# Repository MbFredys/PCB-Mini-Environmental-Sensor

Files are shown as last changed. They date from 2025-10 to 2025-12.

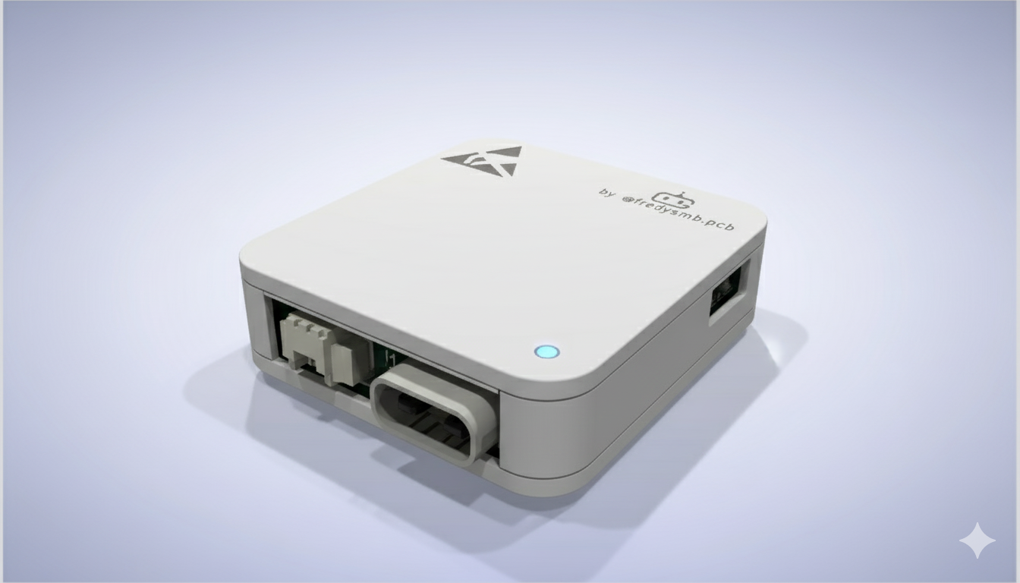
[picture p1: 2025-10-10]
Release/Carcaza 1.png

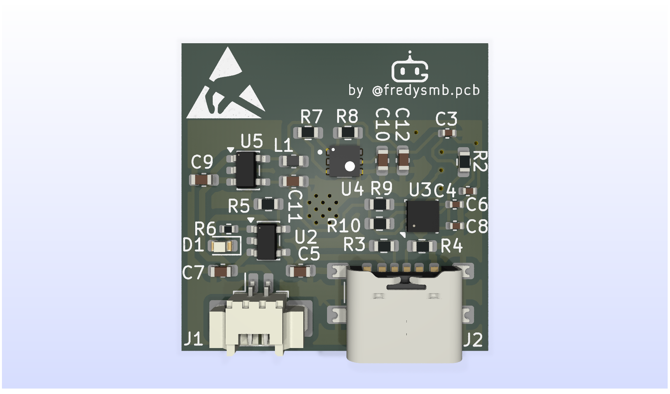
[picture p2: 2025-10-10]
Release/Bottom.png

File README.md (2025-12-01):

# PCB-Mini-Environmental-Sensor


This is a compact environmental monitoring PCB design that enables precise tracking of multiple atmospheric parameters with the following features:

1. 🌡️ Monitors temperature, humidity, and atmospheric pressure using BME280 sensor
2. 💨 Measures air quality and CO2 equivalent with Sensirion SPG40 sensor
3. 📶 WiFi and Bluetooth connectivity via ESP32-C3-VROOM-02 microcontroller
4. 🔋 Battery-powered operation with 3.7V Li-ion battery and USB-C charging
5. ⚡ Efficient power management using TPS62203 step-down converter
6. 🔄 Automatic data logging with cloud connectivity capabilities
7. 💤 Ultra-low power consumption with deep sleep mode
8. 🌧️ Weather-resistant design suitable for indoor and outdoor use

# Usage
To use the environmental sensor node, follow these steps:

  1. Power the device using either the 3.7V battery or USB-C connection
  2. Place the sensor in your desired monitoring location (indoor or outdoor)
  3. Connect to WiFi using the device's configuration interface
  4. Monitor environmental data in real-time through the web dashboard
  5. Analyze historical trends
  6. Receive alerts when environmental parameters exceed safe levels

The device automatically optimizes power consumption by entering deep sleep between measurements, ensuring extended battery life while providing continuous environmental monitoring for smart home, agricultural, and industrial applications.

# Getting Started
To get started with the Environmental Sensor Node PCB design, follow these steps:

  1. Clone this repository to your local machine
  2. Open the PCB design files in your preferred EDA software (KiCAD recommended)
  3. Review the schematic and layout - pay special attention to:
  4. RF antenna keep-out zone for ESP32-C3
  5. I2C routing between sensors and microcontroller
  6. Power distribution network
  7. Send the files to PCBWay for professional fabrication

# Hardware Setup
After receiving your PCBs, solder components in this recommended order:

  1. Power section (TPS62203, MCP73831)
  2. ESP32-C3 module
  3. Sensors (BME280, SPG40)
  4. Passive components and connectors
  5. Program the ESP32-C3 via USB-C connection
  6. Connect a 3.7V Li-ion battery to the battery connector
  7. Test each sensor

# Contributing
If you would like to contribute to the Environmental Sensor Node project, please follow these steps:

  1. Fork this repository
  2. Create a feature branch (git checkout -b feature/improvement)
  3. Make your enhancements - consider:
  4. Power optimization techniques
  5. Additional sensor support
  6. Improved enclosure designs
  7. Localization for different regions
  8. Test your changes thoroughly
  9. Submit a pull request with detailed description

# Areas for Contribution
1. 🔋 Power management algorithms
2. 📡 Wireless protocol optimizations
3. 🌡️ Sensor calibration procedures
4. 🏠 Enclosure designs for different environments
5. 📊 Data visualization interfaces
6. 🔧 Manufacturing improvements

# License
This project is licensed under the CERN Open Hardware Licence Version 2 - Weakly Reciprocal (CERN-OHL-W-2.0).
See the [CERN-OHL-W-2.0 ↗](https://gitlab.com/ohwr/project/cernohl/-/wikis/uploads/82b567f43ce515395f7ddbfbad7a8806/cern_ohl_w_v2.txt) file for more information.

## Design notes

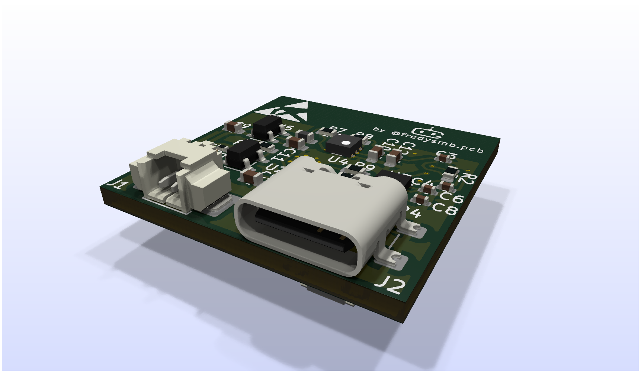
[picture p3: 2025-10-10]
Release/3D-1.png

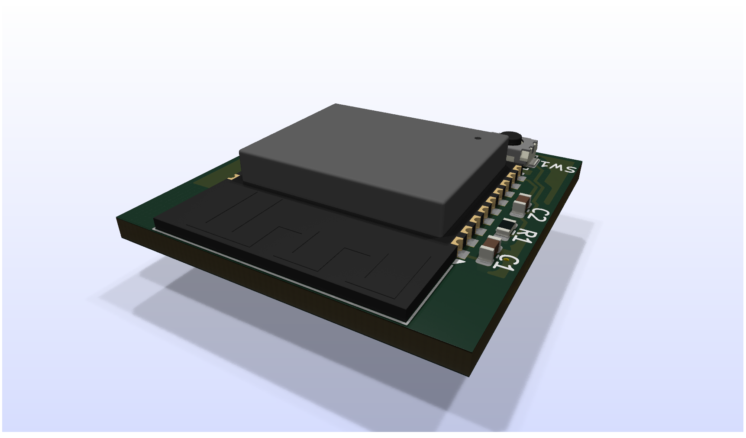
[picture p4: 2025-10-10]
Release/3D-2.png

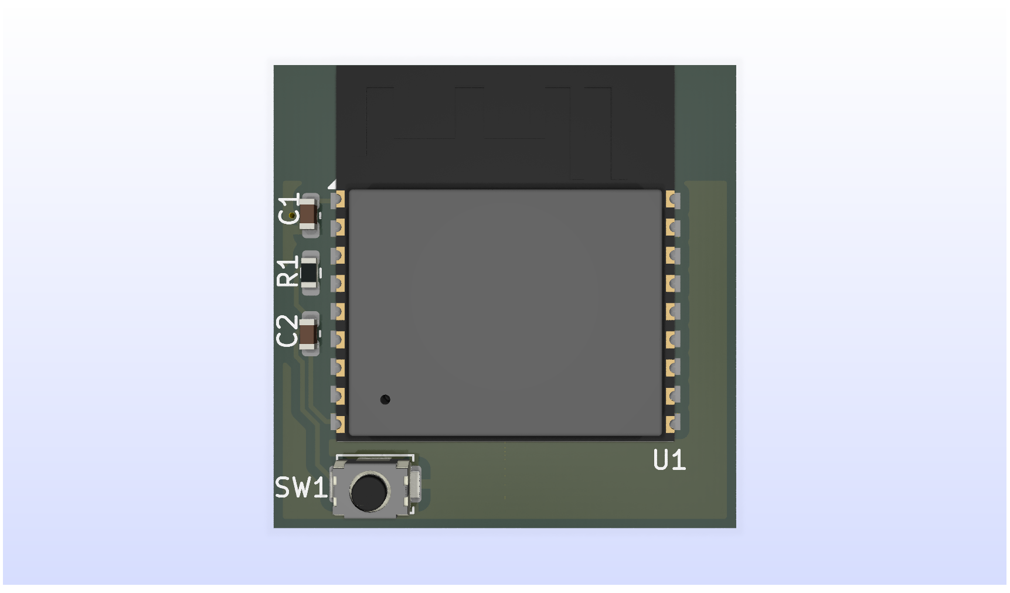
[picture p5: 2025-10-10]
Release/Top.png

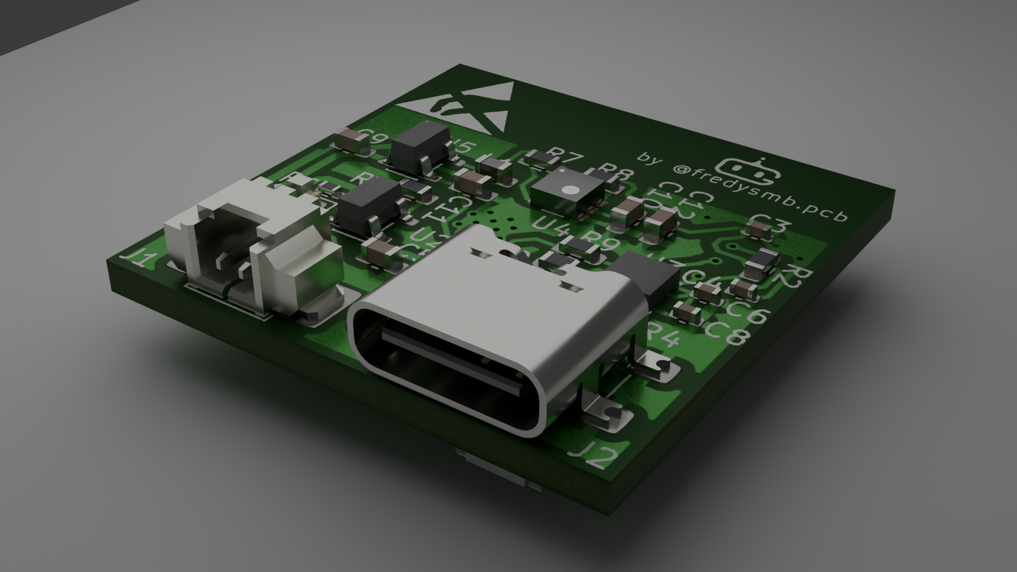
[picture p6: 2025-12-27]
Release/3d-pro.png

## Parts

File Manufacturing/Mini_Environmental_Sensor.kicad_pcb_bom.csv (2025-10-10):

Designator | Quantity | Value | Footprint | Package | MPN | DNP | Mount_Type | Description | LCSC PN | Sim.Pins
C1 | 1 | 10uF | C_0603_1608Metric | 0603 | CL10A106KP8NNNC |  | smt | Unpolarized capacitor | C19702
C10, C12, C2 | 3 | 1uF | C_0603_1608Metric | C20524683 | SMDTC04100VA00MS00 |  | smt | Unpolarized capacitor | C29266
C11, C5, C7, C9 | 4 | 4.7uF | C_0603_1608Metric | 0603 | CL10A475KP8NNNC |  | smt | Unpolarized capacitor | C1705
C3, C4, C6, C8 | 4 | 0.1uF | C_0402_1005Metric | 0402 | CL05B104KO5NNNC |  | smt | Unpolarized capacitor | C1525
D1 | 1 | LED | LED_0603_1608Metric |  |  |  | smt | Light emitting diode |  | 1=K 2=A
J1 | 1 | BAT_Connector | Molex_PicoBlade_53261-0271_1x02-1MP_P1.25mm_Horizontal | SMD,P=1.25mm,Surface Mount,Right Angle | 532610271 |  | smt | Generic connector, single row, 01x02, script generated (kicad-library-utils/schlib/autogen/connector/) | C177225
J2 | 1 | USB_C_PowerOnly | USB_C_Receptacle_GCT_USB4135-GF-A_6P_TopMnt_Horizontal | USB-C_6P_SMD | USB4135-GF-A |  | smt | USB Power-Only 6P Type-C Receptacle connector | C5438410
L1 | 1 | 10uH | L_0603_1608Metric |  |  |  | smt | Inductor
R1, R2, R3, R4 | 4 | 10k | R_0603_1608Metric | 0603 | RC0603FR-0710KL |  | smt | Resistor | C98220
R10, R7, R8, R9 | 4 | 4.7k | R_0603_1608Metric | 0603 | RC0603FR-074K7L |  | smt | Resistor | C99782
R5 | 1 | 2k | R_0603_1608Metric | 0603 | RC0603FR-072KL |  | smt | Resistor | C105576
R6 | 1 | 470 | R_0402_1005Metric | 0402 | 0402WGF4700TCE |  | smt | Resistor | C25117
SW1 | 1 | SW_Push | SW_Push_SPST_NO_Alps_SKRK | SMD,3.9x2.9mm | SKRKAEE020 |  | smt | Push button switch, generic, two pins | C115357
U1 | 1 | ESP32-C3-WROOM-02 | ESP32-C3-WROOM-02 | VFQFN-32-EP | ESP32-C3-WROOM-02-N4 |  | smt | 802.11 b/g/n Wi-Fi and Bluetooth 5 module, ESP32-C3 SoC, RISC-V microprocessor, On-board antenna | C2934560
U2 | 1 | MCP73831 | SOT-23-5 | SOT-23-5 | MCP73831T-2ACI/OT |  | smt | Single cell, Li-Ion/Li-Po charge management controller, 4.50V, Tri-State Status Output, in SOT23-5 package | C424093
U3 | 1 | BME280 | Bosch_LGA-8_2.5x2.5mm_P0.65mm_ClockwisePinNumbering | LGA-8(2.5x2.5) | BME280 |  | smt | 3-in-1 sensor, humidity, pressure, temperature, I2C and SPI interface, 1.71-3.6V, LGA-8 | C92489
U4 | 1 | SGP40-D-R4 | XCDR_SGP40-D-R4 | DFN-4 | SGP40-D-R4 |  | smt
U5 | 1 | TPS62203 | SOT-23-5 | SOT-23-5 | TPS62203DBVR |  | smt | 300mA High-Efficiency Step-Down DC-DC Converter, adjustable output voltage, 2.5-6V input voltage, SOT-23-5 | C9051

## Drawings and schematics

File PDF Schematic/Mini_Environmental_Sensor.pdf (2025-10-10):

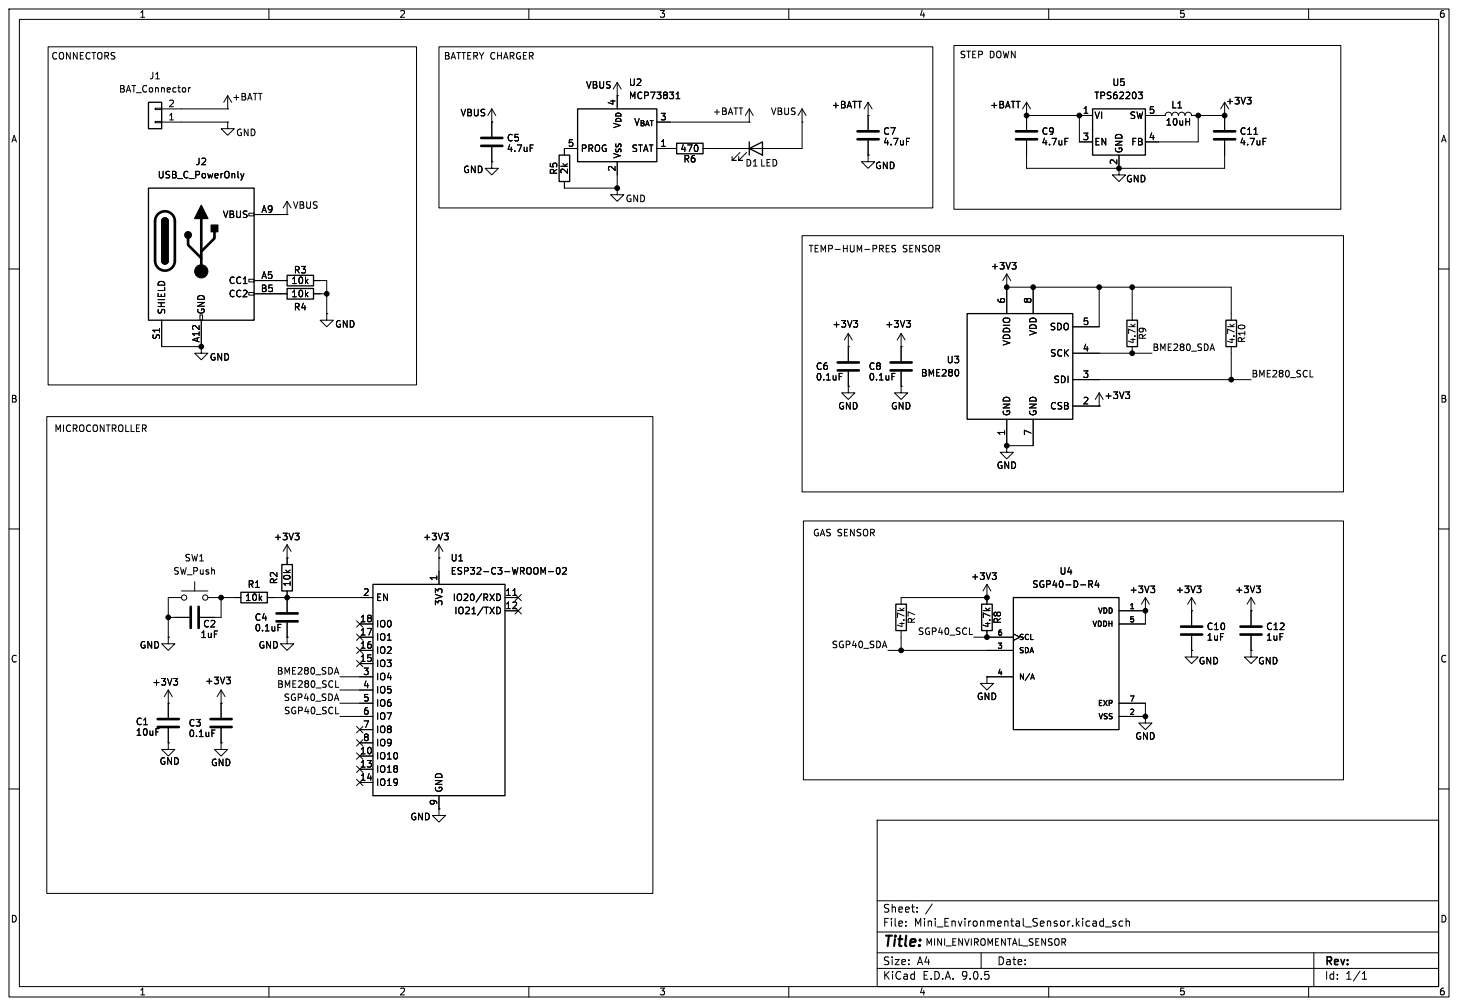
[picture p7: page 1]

7 SDO 5 SCK 4 SDI 3 CSB 2 U3 BME280 C6

7 SDO 5 SCK 4 SDI 3 CSB 2 C6

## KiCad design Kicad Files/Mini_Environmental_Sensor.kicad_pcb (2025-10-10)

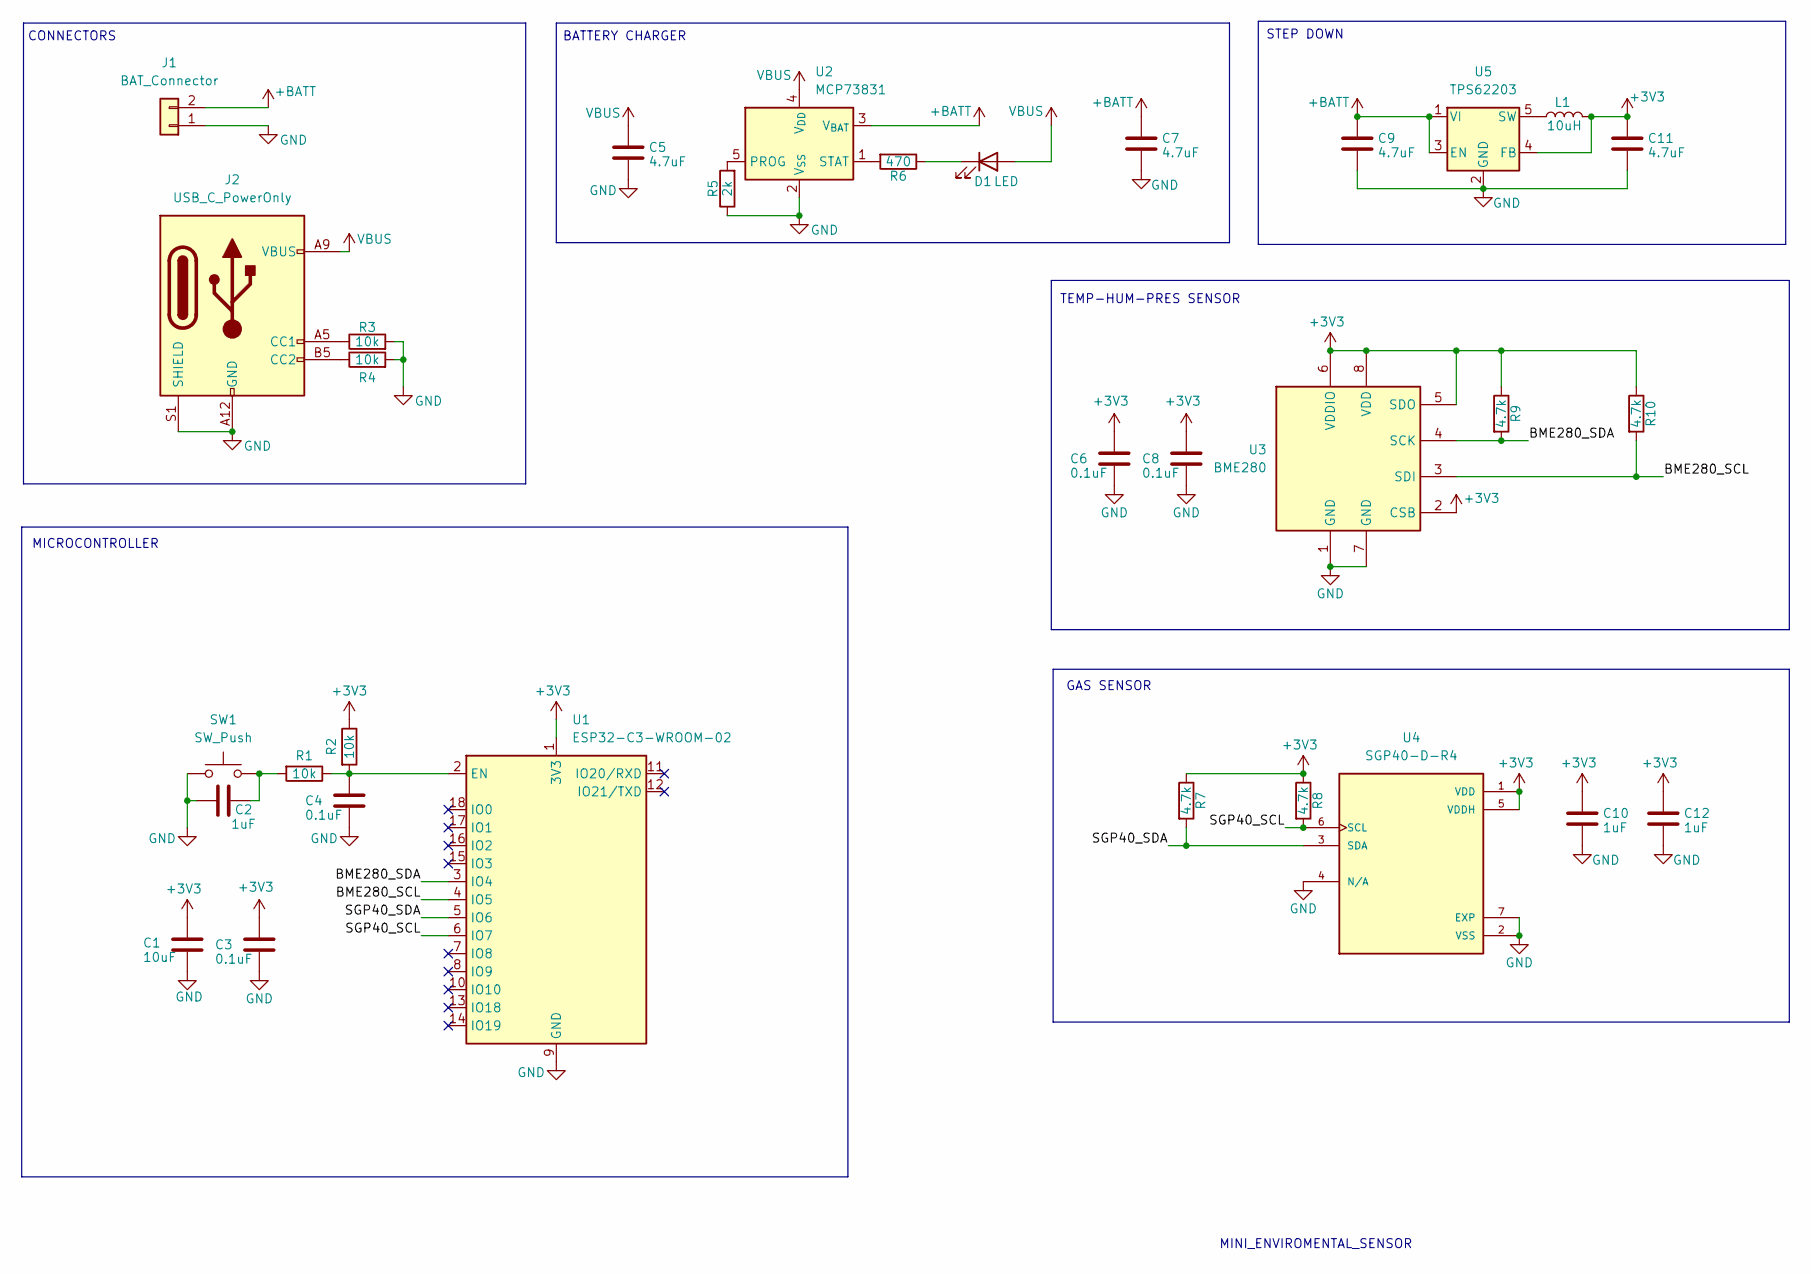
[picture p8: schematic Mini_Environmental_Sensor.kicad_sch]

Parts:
C1: 10uF; C_0603_1608Metric; MPN CL10A106KP8NNNC; LCSC PN C19702
C2, C10, C12: 1uF; C_0603_1608Metric; MPN SMDTC04100VA00MS00; LCSC PN C29266
C3, C4, C6, C8: 0.1uF; C_0402_1005Metric; MPN CL05B104KO5NNNC; LCSC PN C1525
C5, C7, C9, C11: 4.7uF; C_0603_1608Metric; MPN CL10A475KP8NNNC; LCSC PN C1705
D1: LED; LED_0603_1608Metric
J1: BAT_Connector; Molex_PicoBlade_53261-0271_1x02-1MP_P1.25mm_Horizontal; MPN 532610271; LCSC PN C177225
J2: USB_C_PowerOnly; USB_C_Receptacle_GCT_USB4135-GF-A_6P_TopMnt_Horizontal; MPN USB4135-GF-A; LCSC PN C5438410
L1: 10uH; L_0603_1608Metric
R1, R2, R3, R4: 10k; R_0603_1608Metric; MPN RC0603FR-0710KL; LCSC PN C98220
R5: 2k; R_0603_1608Metric; MPN RC0603FR-072KL; LCSC PN C105576
R6: 470; R_0402_1005Metric; MPN 0402WGF4700TCE; LCSC PN C25117
R7, R8, R9, R10: 4.7k; R_0603_1608Metric; MPN RC0603FR-074K7L; LCSC PN C99782
SW1: SW_Push; SW_Push_SPST_NO_Alps_SKRK; MPN SKRKAEE020; LCSC PN C115357
U1: ESP32-C3-WROOM-02; MPN ESP32-C3-WROOM-02-N4; LCSC PN C2934560
U2: MCP73831; SOT-23-5; MPN MCP73831T-2ACI/OT; LCSC PN C424093
U3: BME280; Bosch_LGA-8_2.5x2.5mm_P0.65mm_ClockwisePinNumbering; MPN BME280; LCSC PN C92489
U4: SGP40-D-R4; XCDR_SGP40-D-R4; MPN SGP40-D-R4
U5: TPS62203; SOT-23-5; MPN TPS62203DBVR; LCSC PN C9051

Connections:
+3V3: C1.1, C3.1, C6.1, C8.1, C10.1, C11.1, C12.1, L1.2, R2.1, R7.1, R8.1, R9.1, R10.1, U1.1 (3V3), U3.2 (CSB), U3.5 (SDO), U3.6 (VDDIO), U3.8 (VDD), U4.1 (VDD), U4.5 (VDDH), U5.4 (FB)
+BATT: C7.1, C9.1, J1.2, U2.3 (V_{BAT}), U5.1 (VI), U5.3 (EN)
/BME280_SCL: R10.2, U1.4 (IO5), U3.3 (SDI)
/BME280_SDA: R9.2, U1.3 (IO4), U3.4 (SCK)
/SGP40_SCL: R8.2, U1.6 (IO7), U4.6 (SCL)
/SGP40_SDA: R7.2, U1.5 (IO6), U4.3 (SDA)
GND: C1.2, C2.2, C3.2, C4.2, C5.2, C6.2, C7.2, C8.2, C9.2, C10.2, C11.2, C12.2, J1.1, J2.A12 (GND), J2.B12 (GND), J2.S1 (SHIELD), R3.2, R4.2, R5.1, SW1.1, U1.9 (GND), U1.19 (GND), U2.2 (V_{SS}), U3.1 (GND), U3.7 (GND), U4.2 (VSS), U4.4 (N/A), U4.7 (EXP), U5.2 (GND)
unnamed: C2.1, R1.2, SW1.2
unnamed: D1.1 (K), R6.1
unnamed: J2.A5 (CC1), R3.1
unnamed: J2.B5 (CC2), R4.1
unnamed: C4.1, R1.1, R2.2, U1.2 (EN)
unnamed: R5.2, U2.5 (PROG)
unnamed: R6.2, U2.1 (STAT)
unnamed: L1.1, U5.5 (SW)
VBUS: C5.1, D1.2 (A), J2.A9 (VBUS), J2.B9 (VBUS), U2.4 (V_{DD})

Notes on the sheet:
MINI_ENVIROMENTAL_SENSOR
GAS SENSOR
BATTERY CHARGER
STEP DOWN
MICROCONTROLLER
CONNECTORS
TEMP-HUM-PRES SENSOR

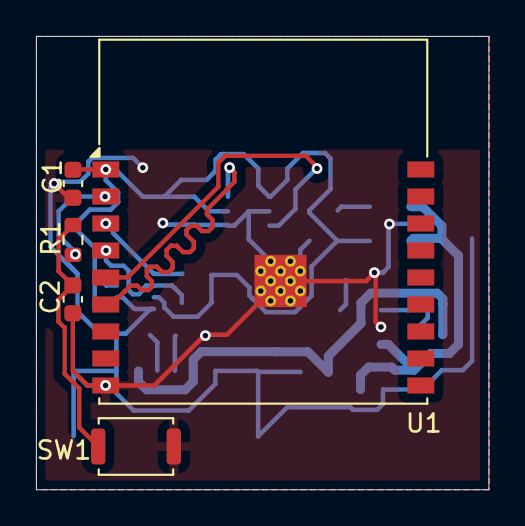
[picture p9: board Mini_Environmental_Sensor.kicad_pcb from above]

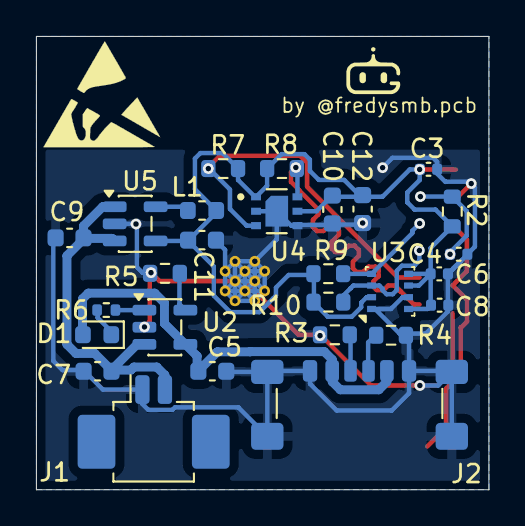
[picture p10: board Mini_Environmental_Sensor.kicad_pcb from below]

Board: 2 copper layers, 25.1 x 25.2 mm, 32 parts (27 on the bottom side), 16 nets.

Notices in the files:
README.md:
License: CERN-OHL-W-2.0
